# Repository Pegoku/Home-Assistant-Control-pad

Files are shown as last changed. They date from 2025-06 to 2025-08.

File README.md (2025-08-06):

# Home-Assistant-Control-pad

This is a programmable Home Assistant Control Pad. It can control 4 Home assistant devices at a time, and has 4 togglable screens/zones (in total 16 devices). It uses buttons and rotary encoders to enable and control other HASS devices. It also has an OLED Display (1.33") to display the status of the devices. It is battery powered, it contains a 1800mAh Li-Po. The device uses an ESP32-S2 and ESPHome.

## Why I made it?

I made this project as I wanted an easy and fast way to control the "smart" devices I have made. I'm making quite a few ESPHome devices and wanted something to control most of them easily.

## Features

- Controls Home Assistant entities (lights, switches, etc.)
- Over-the-air (OTA) updates

## Images

Final Build: 

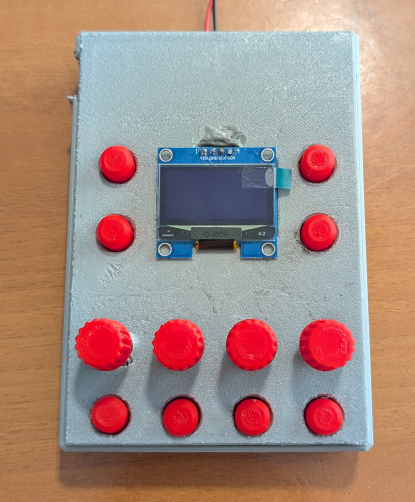
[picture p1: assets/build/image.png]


<details>
  <summary>Case</summary>

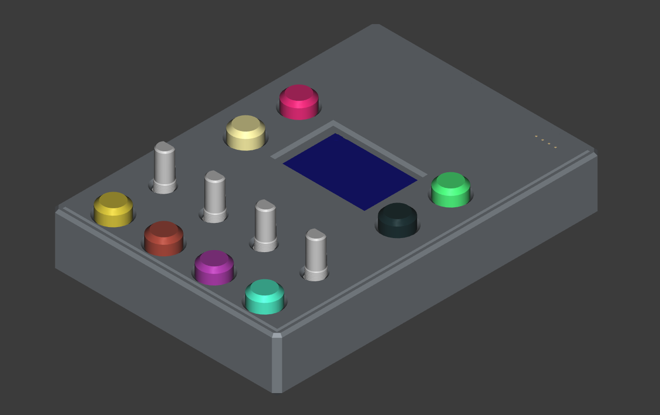
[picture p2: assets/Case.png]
Final


</details>
<details>
  <summary>Schematic</summary>
  
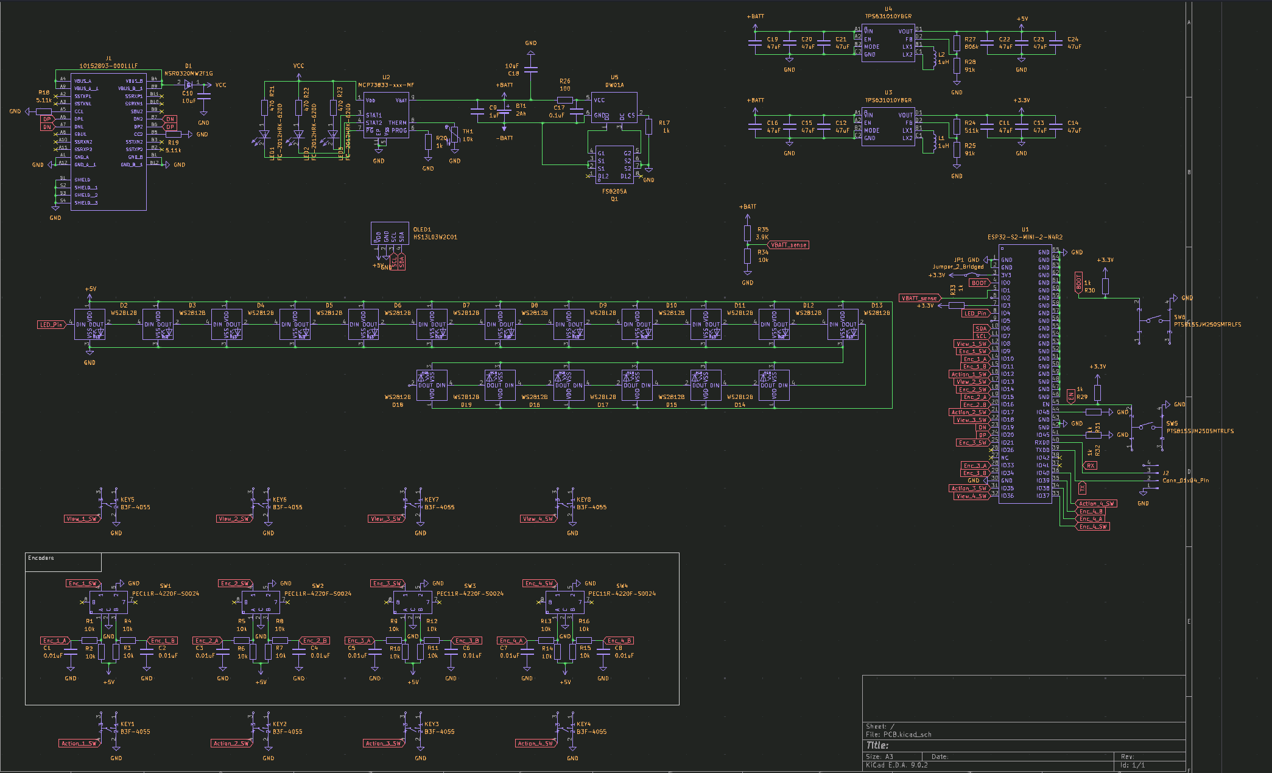
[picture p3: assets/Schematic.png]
schematic


</details>
<details>
  <summary>PCB</summary>

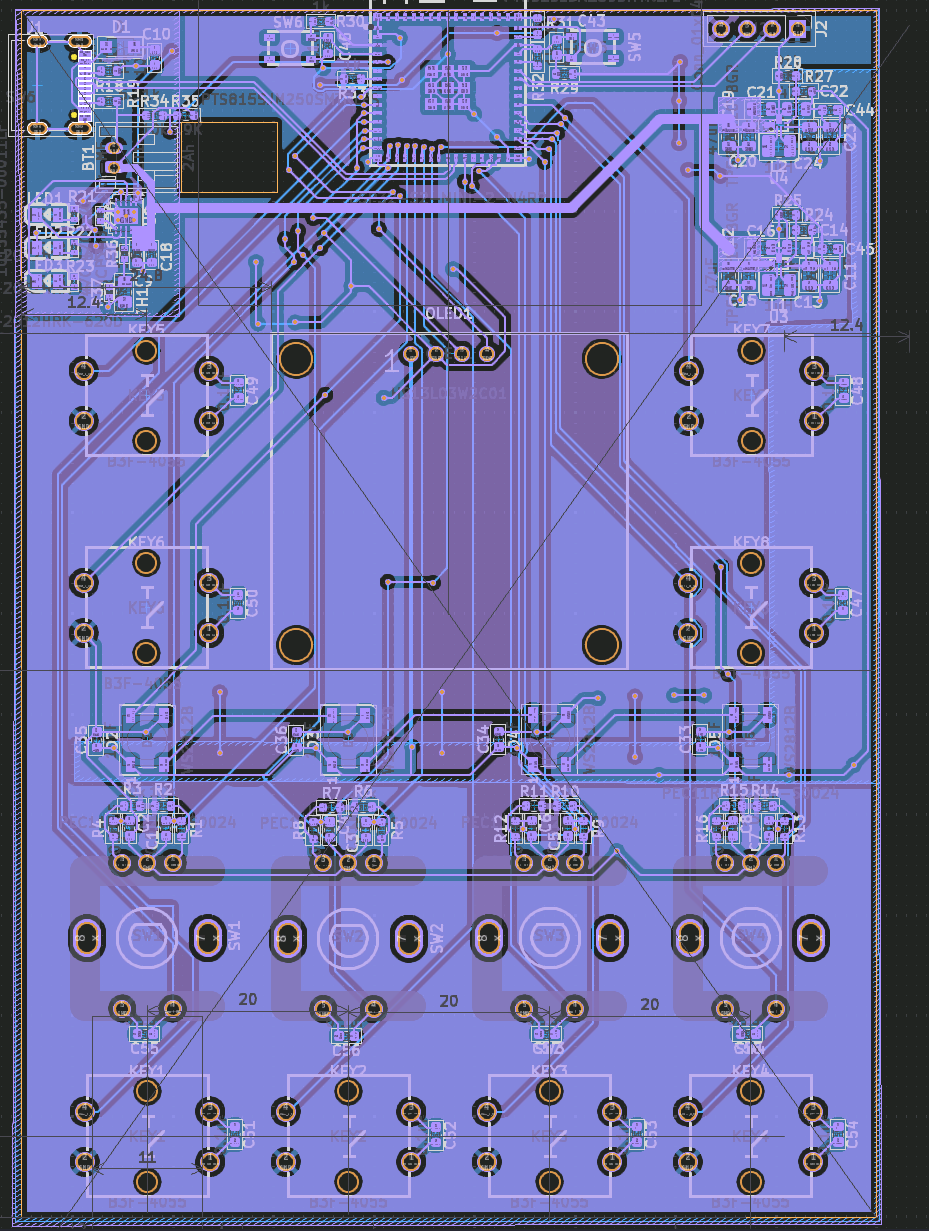
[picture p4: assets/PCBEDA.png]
PCB design

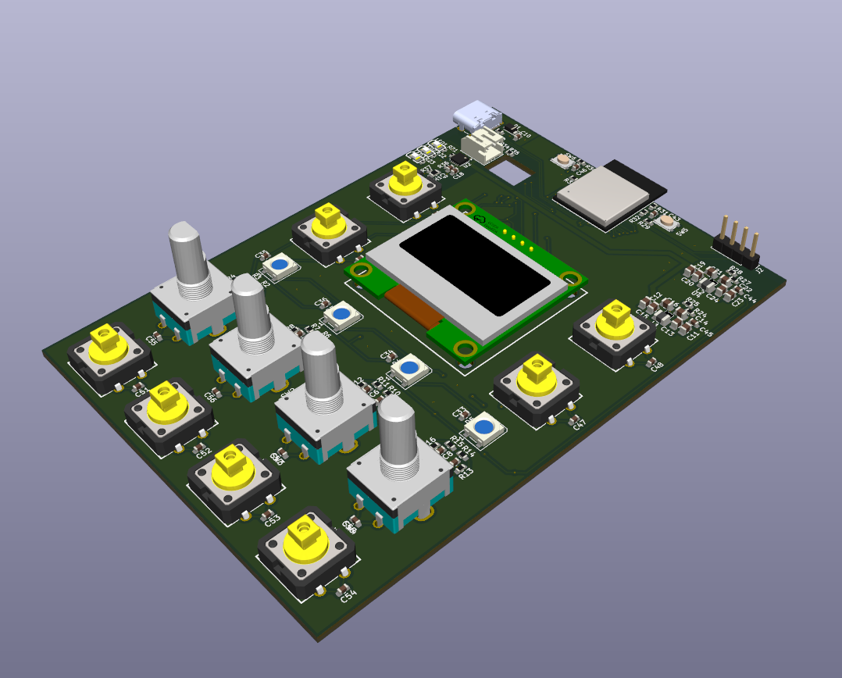
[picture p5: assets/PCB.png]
PCB render


</details>

## BOM

| Index | Part Number | What the item is for in your project | Description | Pack Quantity | ID | Unit Price | Total Price | Total |
| ----- | --- | --- | --- | --- | --- | --- | --- | --- |
| 1 | PMEG10010ELRX | Reverse polarity protection | DIODE SCHOTTKY 100V 1A SOD123W | 2 | 1727+AC0-2394+AC0-1+AC0-ND | $0.27 | $0.54 | $133.08 |
| 2 | DFE252012P+AC0-1R0M+AD0-P2 | Inductor for buck+AC0-boost | FIXED IND 1UH 3.2A 0.042OHM SMD | 3 | 490+AC0-10647+AC0-1+AC0-ND | $0.22 | $0.66 |
| 3 | LS R976+AC0-NR+AC0-1+AC0-0+AC0-20+AC0-R18 | Led indication | LED RED DIFFUSED 0805 SMD | 3 | 475+AC0-LSR976+AC0-NR+AC0-1CT+AC0-ND | $0.15 | $0.45 |
| 4 | LG R971+AC0-KN+AC0-1+AC0-0+AC0-20+AC0-R18 | Led indication | LED GREEN DIFFUSED 0805 SMD | 3 | 475+AC0-LGR971+AC0-KN+AC0-1CT+AC0-ND | $0.15 | $0.45 |
| 5 | LTST+AC0-C170KSKT | Led indication | LED YELLOW CLEAR SMD | 3 | 160+AC0-1416+AC0-1+AC0-ND | $0.17 | $0.51 |
| 6 | RMCF0603JT10K0 | Passive | RES 10K OHM 5% 1/10W 0603 | 22 | RMCF0603JT10K0CT+AC0-ND | $0.02 | $0.42 |
| 7 | CRCW06035K11FKEAC | Passive | RES 5.11K OHM 1% 1/10W 0603 | 3 | 541+AC0-5491+AC0-1+AC0-ND | $0.10 | $0.30 |
| 8 | RC0402FR+AC0-071KL | Passive | RES 1K OHM 1% 1/16W 0402 | 2 | 311+AC0-1.00KLRCT+AC0-ND | $0.10 | $0.20 |
| 9 | RC0402FR+AC0-07470RL | Passive | RES 470 OHM 1% 1/16W 0402 | 4 | 311+AC0-470LRCT+AC0-ND | $0.10 | $0.40 |
| 10 | RC0603FR+AC0-07511KL | Passive | RES 511K OHM 1% 1/10W 0603 | 2 | 311+AC0-511KHRCT+AC0-ND | $0.10 | $0.20 |
| 11 | RC0603FR+AC0-0791KL | Passive | RES 91K OHM 1% 1/10W 0603 | 3 | 311+AC0-91.0KHRCT+AC0-ND | $0.10 | $0.30 |
| 12 | RC0603FR+AC0-07806KL | Passive | RES 806K OHM 1% 1/10W 0603 | 2 | 311+AC0-806KHRCT+AC0-ND | $0.10 | $0.20 |
| 13 | RC0603FR+AC0-071KL | Passive | RES 1K OHM 1% 1/10W 0603 | 13 | 311+AC0-1.00KHRCT+AC0-ND | $0.01 | $0.12 |
| 14 | RC0603FR+AC0-073K9L | Passive | RES 3.9K OHM 1% 1/10W 0603 | 2 | 311+AC0-3.90KHRCT+AC0-ND | $0.10 | $0.20 |
| 15 | RC0402FR+AC0-071K54L | Passive | RES 1.54K OHM 1% 1/16W 0402 | 2 | YAG3040CT+AC0-ND | $0.10 | $0.20 |
| 16 | RC0402FR+AC0-0769K8L | Passive | RES 69.8K OHM 1% 1/16W 0402 | 2 | YAG3216CT+AC0-ND | $0.10 | $0.20 |
| 17 | PEC11R+AC0-4220F+AC0-S0024 | Rotate action | ROTARY ENCODER MECHANICAL 24PPR | 7 | PEC11R+AC0-4220F+AC0-S0024+AC0-ND | $1.89 | $13.23 |
| 18 | PTS815SJG250SMTR LFS | Esp32 buttons | SWITCH TACTILE SPST+AC0-NO 0.05A 12V | 3 | CKN12217+AC0-1+AC0-ND | $0.28 | $0.84 |
| 19 | TX08F103F3435ER | NTC Thermistor | THERMISTOR 0805 10K/3435 | 2 | 273+AC0-TX08F103F3435ERCT+AC0-ND | $0.12 | $0.24 |
| 20 | ESP32+AC0-S2+AC0-MINI+AC0-2+AC0-N4R2 | MCU | RF TXRX MOD WIFI PCB TRACE SMD | 2 | 1965+AC0-ESP32+AC0-S2+AC0-MINI+AC0-2+AC0-N4R2CT+AC0-ND | $4.31 | $8.62 |
| 21 | MCP73833T+AC0-FCI/MF | Battery charger | IC BATT CONTRL LI+AC0-ION 1CEL 10DFN | 2 | MCP73833T+AC0-FCI/MFCT+AC0-ND | $1.14 | $2.28 |
| 22 | TPS631010YBGR | Buck+AC0-Boost | IC REG BUCK BST ADJ 1.5A 8DSBGA | 3 | 296+AC0-TPS631010YBGRCT+AC0-ND | $1.29 | $3.87 |
| 23 | C0603C103J5REC7411 | Passive | CAP CER SMD 0603 .01UF 5% X7R 50 | 13 | 399+AC0-17568+AC0-1+AC0-ND | $0.10 | $1.33 |
| 24 | C0603C104J5REC7411 | Passive | CAP CER 0603 | 20 | 399+AC0-C0603C104J5REC7411CT+AC0-ND | $0.11 | $2.24 |
| 25 | CL10A105KQ8NNNC | Passive | CAP CER 1UF 6.3V X5R 0603 | 2 | 1276+AC0-1036+AC0-1+AC0-ND | $0.10 | $0.20 |
| 26 | CL10A106KQ8NNNC | Passive | CAP CER 10UF 6.3V X5R 0603 | 13 | 1276+AC0-1038+AC0-1+AC0-ND | $0.03 | $0.39 |
| 27 | CL21A476MQYNNNG | Passive | CAP CER 47UF 6.3V X5R 0805 | 15 | 1276+AC0-6467+AC0-1+AC0-ND | $0.16 | $2.37 |
| 28 | 16347 | Led indication | ADDRESS LED RED/GRN/BLUE | 5 | 1568+AC0-16347CT+AC0-ND | $0.68 | $3.40 |
| 29 | B3F+AC0-4055 | Push Action | SWITCH TACTILE SPST+AC0-NO 0.05A 24V | 10 | SW414+AC0-ND | $0.42 | $4.23 |
| 30 | S2B+AC0-PH+AC0-K+AC0-S | Battery connector | CONN HEADER R/A 2POS 2MM | 2 | 455+AC0-1719+AC0-ND | $0.11 | $0.22 |
| 31 | PCB | PCB | | 1 | https://aisler.net | $42.57 | $42.57 |
| 32 | Battery | Power Source | 103450 1800mAh | 1 | https://www.ebay.es/itm/255510046348 | $15.44 | $15.44 |
| 33 | Display | Displays The UI | I2C display | 1 | https://es.aliexpress.com/item/1005006862867338.html | $2.62 | $2.62 |
| 34 | Rubber Feet | Adds friction to the base so it doesn+IBk-t slip | | 1 | https://es.aliexpress.com/item/1005005275590870.html | $3.11 | $3.11 |
| 35 | ELEGOO PLA filament | Printing case | | 1 | https://www.amazon.es/-/en/Filament-Printer-Dimensional-Accuracy-Printers/dp/B0CD77VHBZ | $20.53 | $20.53 |

## Configuration

Remember to set your secrets in [secrets.yaml](Code/secrets.example.yaml).

All firmware configuration lives in [code.yaml](Code/code.yaml):
PS: This configuration is for reference only, The final configuration will be for the ESP32-S2. You'll also have to configure the devices you want to control in Home Assistant.
```yaml
esphome:
  name: controlpad
  friendly_name: ControlPad

esp32:
  board: esp32-c3-devkitm-1
  framework:
    type: arduino

# Enable logging
logger:

# Enable Home Assistant API
api:
  encryption:
    key: !secret api_key

ota:
  - platform: esphome
    password: !secret ota_password

wifi:
  ssid: !secret wifi_ssid
  password: !secret wifi_password

  # Enable fallback hotspot (captive portal) in case wifi connection fails
  ap:
    ssid: "Controlpad Fallback Hotspot"
    password: "wHjqyQOLnaPa"

globals:
  - id: page_active
    type: int
    initial_value: "0"

i2c:
  sda: GPIO6
  scl: GPIO7
  frequency: 800kHz
  scan: true

binary_sensor:
  - platform: gpio
    pin:
      number: GPIO2
      mode: INPUT_PULLUP
      inverted: true
    name: "Button1"
    on_press:
      - display.page.show: page1
      - lambda: |-
          id(page_active) = 1;

  - platform: gpio
    pin:
      number: GPIO4
      mode: INPUT_PULLUP
      inverted: true
    name: "Button2"
    on_press:
      - display.page.show: page2
      - lambda: |-
          id(page_active) = 2;

  - platform: gpio
    pin:
      number: GPIO21
      mode: INPUT_PULLUP
      inverted: true
    name: "toggle1"
    on_press:
      then:
        - if:
            condition:
              lambda: |-
                return id(page_active) == 1;
            then:
              - homeassistant.service:
                  service: light.toggle
                  data:
                    entity_id: light.led_controller_1_light_bar

sensor:
  - platform: homeassistant
    name: "Bar Light Brightness"
    id: led_controller_1_light_bar_brightness
    entity_id: light.led_controller_1_light_bar
    attribute: brightness
    unit_of_measurement: "%"
    filters:
      - lambda: |-
          if (isnan(x)) return 0.0f;
          return int(x * 100.0f / 255.0f);

  - platform: adc
    pin: GPIO3
    name: "potentiometer1"
    id: potentiometer1
    attenuation: 12db # allow 0–3.3 V range
    update_interval: 20ms
    unit_of_measurement: "%"
    filters:
      - sliding_window_moving_average:
          window_size: 10
          send_every: 5
      - lambda: |-
          if (isnan(x)) return 0.0f;
          int pot_val = int(x * 100.0f / 2.9f);
          if (pot_val > 100) pot_val = 100;
          return pot_val;
      - delta: 1.0

    on_value:
      then:
        - if:
            condition:
              lambda: |-
                return id(page_active) == 1;
            then:
              - homeassistant.service:
                  service: light.turn_on
                  data:
                    entity_id: light.led_controller_1_light_bar
                    brightness_pct: !lambda "return (int)x;"

# SH1106 128×64 over I2C
display:
  - platform: ssd1306_i2c
    model: SH1106 128x64
    id: display1
    address: 0x3C
    rotation: 0
    update_interval: 100ms
    pages:
      - id: page1
        lambda: |-
          int val1 = int((id(led_controller_1_light_bar_brightness).state / 100.0f) * 31);
          if (val1 != 0) {
            val1 += 1;
          }
          it.filled_rectangle(10, 64-val1, 5, 33);

          // it.printf(0, 0, id(font1), "%.0f%%", id(led_controller_1_light_bar_brightness).state);
      - id: page2
        lambda: |-
          it.print(0, 10, id(font1), "This is page 2!");
          it.filled_rectangle(10, 20, 80, 5);

font:
  - file: "gfonts://Ubuntu"
    id: font1
    size: 20

captive_portal:
```

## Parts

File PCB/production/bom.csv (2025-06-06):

 | Footprint | Quantity | Value | LCSC Part #
BT1 | JST_PH_S2B-PH-K_1x02_P2.00mm_Horizontal | 1 | 2Ah
C1, C2, C3, C4, C5, C6, C7, C8 | 0603 | 8 | 0.01uF
C10, C18, C33, C34, C35, C36 | 0603 | 6 | 10uF
C11, C12, C13, C14, C15, C16, C19, C20, C21, C22, C23, C24 | 0805 | 12 | 47uF
C43, C44, C45, C46, C47, C48, C49, C50, C51, C52, C53, C54, C55, C56, C57, C58 | 0603 | 16 | 0.1uF
C9 | 0603 | 1 | 1uF
D1 | Nexperia_CFP3_SOD-123W | 1 | D
D2, D3, D4, D5 | LED_WS2812B_PLCC4_5.0x5.0mm_P3.2mm | 4 | WS2812B
J1 | AMPHENOL_10155435-00011LF | 1 | 10155435-00011LF
J2 | PinHeader_1x04_P2.54mm_Vertical | 1 | Conn_01x04_Pin
KEY1, KEY2, KEY3, KEY4, KEY5, KEY6, KEY7, KEY8 | KEY-TH_4P-L12.0-W12.0-P5.00-LS13.4-EH | 8 | B3F-4055 | C84931
L1, L2 | 1008 | 2 | 1uH
LED1, LED2, LED3 | LED0805-R-RD | 3 | FC-2012HRK-620D | C84256
OLED1 | OLED-TH_L35.4-W33.5_HS13L03W2C01 | 1 | HS13L03W2C01 | C7465997
R1, R10, R11, R12, R13, R14, R15, R16, R2, R3, R34, R4, R5, R6, R7, R8, R9 | 0603 | 17 | 10k
R18, R19 | 0603 | 2 | 5.11k
R20 | 0402 | 1 | 1k
R21, R22, R23 | 0402 | 3 | 470
R24 | 0603 | 1 | 511k
R25, R28 | 0603 | 2 | 91k
R27 | 0603 | 1 | 806k
R29, R30, R31, R32, R33 | 0603 | 5 | 1k
R35 | 0603 | 1 | 3.9K
R36 | 0402 | 1 | 1.54k
R37 | 0402 | 1 | 69.8k
SW1, SW2, SW3, SW4 | SW-TH_5P-L12.5-W13.4-P2.50-LS14.5-EH13.2 | 4 | PEC11R-4220F-S0024 | C143797
SW5, SW6 | KEY-SMD_4P-L4.2-W3.25-P2.15-TL | 2 | PTS815SJM250SMTRLFS | C2689510
TH1 | 0805 | 1 | 10k
U1 | WIFI-SMD_ESP32-MINI-1-N4 | 1 | ESP32-S2-MINI-2-N4R2 | C3013908
U2 | DFN-10-1EP_3x3mm_P0.5mm_EP1.58x2.35mm | 1 | MCP73833-xxx-MF
U3, U4 | WLCSP-8_L1.8-W1.0-R4-C2-P0.40-BR | 2 | TPS631010YBGR | C6719123

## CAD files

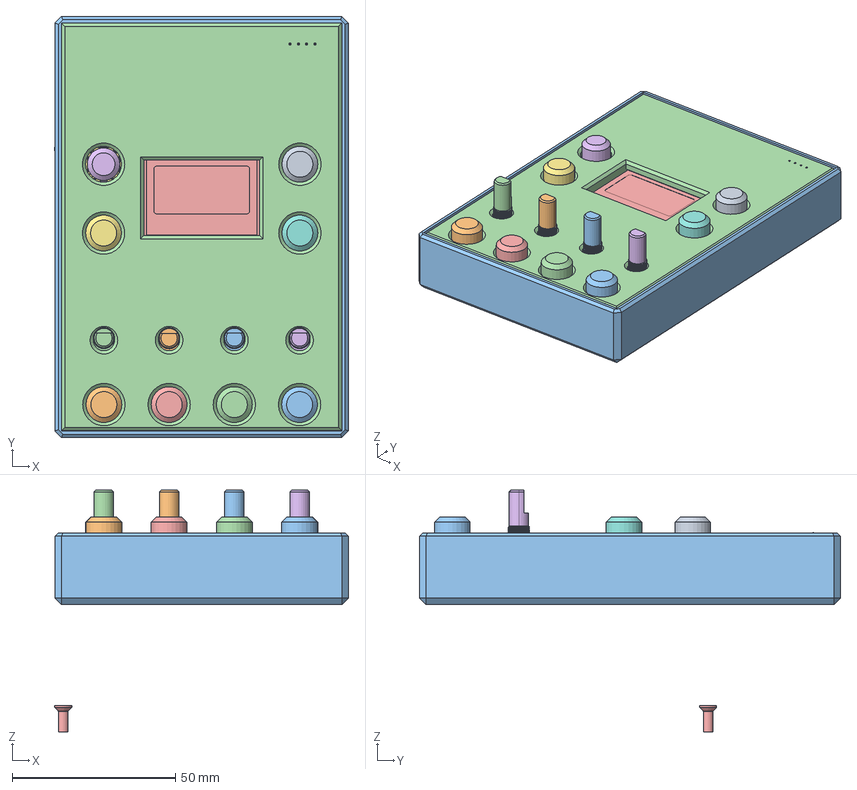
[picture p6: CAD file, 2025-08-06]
CAD/Case.FCStd
90.2 x 129.1 x 74.1 mm
Battery
R_0402_1005Metric006
SW-TH_5P-L12.5-W13.4-P2.50-LS14.5-EH13.006
WLCSP-8_L1.8-W1.0-R4-C2-P0.40-BR002
WIFI-SMD_ESP32-MINI-1-N005
KEY-TH_4P-L12.0-W12.0-H7.5-LS12.5-P5.008
DFN-10-1EP_3x3mm_P0.5mm_EP1.55x2.48mm001
C_0603_1608Metric031
C_0603_1608Metric032
LED_WS2812B_PLCC4_5.0x5.0mm_P3.2mm004
R_0603_1608Metric029
C_0805_2012Metric012
C_0603_1608Metric033
C_0603_1608Metric034
R_0603_1608Metric030
R_0402_1005Metric007
R_0603_1608Metric031
R_0603_1608Metric032
C_0603_1608Metric035
LED0805-RD003
OLED-TH_L35.4-W33.5_HS13L03W2C002
C_0603_1608Metric036
C_0603_1608Metric037
R_0603_1608Metric033
C_0603_1608Metric038
C_0805_2012Metric013
C_0805_2012Metric014
R_0603_1608Metric034
KEY-TH_4P-L12.0-W12.0-H7.5-LS12.5-P5.009
R_0603_1608Metric035
R_0603_1608Metric036
C_0805_2012Metric015
C_0603_1608Metric039
C_0603_1608Metric040
R_0603_1608Metric037
C_0603_1608Metric041
LED_WS2812B_PLCC4_5.0x5.0mm_P3.2mm005
R_0603_1608Metric038
C_0603_1608Metric042
C_0805_2012Metric016
R_0603_1608Metric039
LED0805-RD004
KEY-SMD_4P-L4.2-W3.25-P2.15-TL002
PCB 1.43.002
LED0805-RD005
C_0603_1608Metric043
C_0805_2012Metric017
R_0603_1608Metric040
KEY-TH_4P-L12.0-W12.0-H7.5-LS12.5-P5.010
WLCSP-8_L1.8-W1.0-R4-C2-P0.40-BR003
R_0402_1005Metric008
KEY-TH_4P-L12.0-W12.0-H7.5-LS12.5-P5.011
R_0402_1005Metric009
R_0603_1608Metric041
C_0805_2012Metric018
R_0603_1608Metric042
C_0603_1608Metric044
R_0603_1608Metric043
KEY-TH_4P-L12.0-W12.0-H7.5-LS12.5-P5.012
R_0603_1608Metric044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

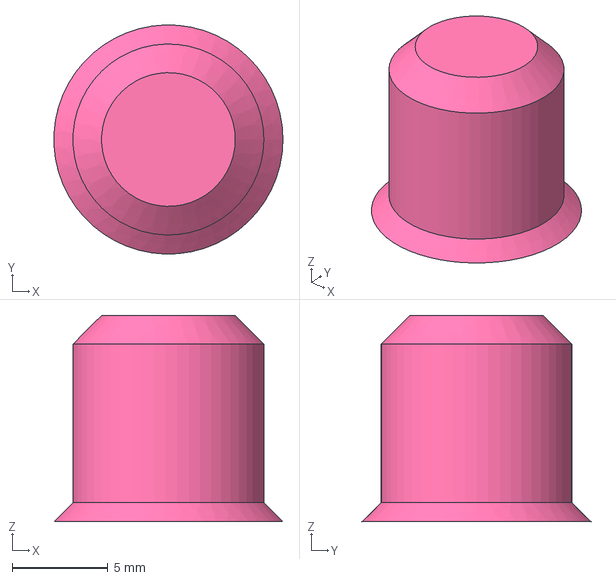
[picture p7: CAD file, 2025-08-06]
CAD/Button.step
12.0 x 12.0 x 10.8 mm

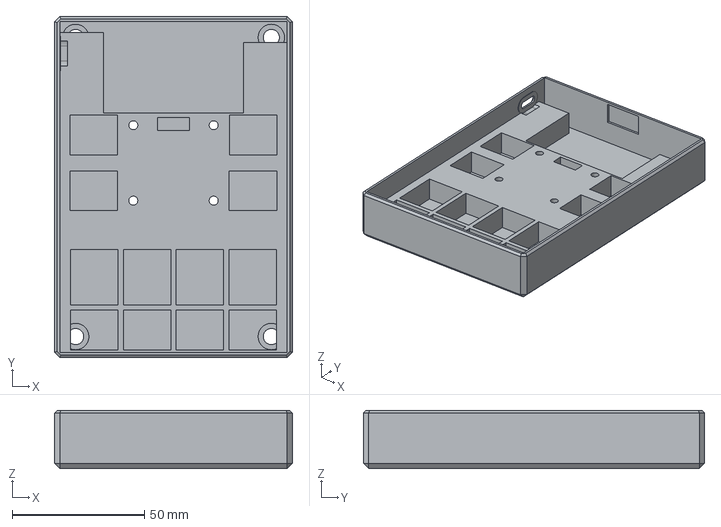
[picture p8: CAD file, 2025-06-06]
CAD/CaseBottom.step
90.0 x 129.1 x 22.0 mm

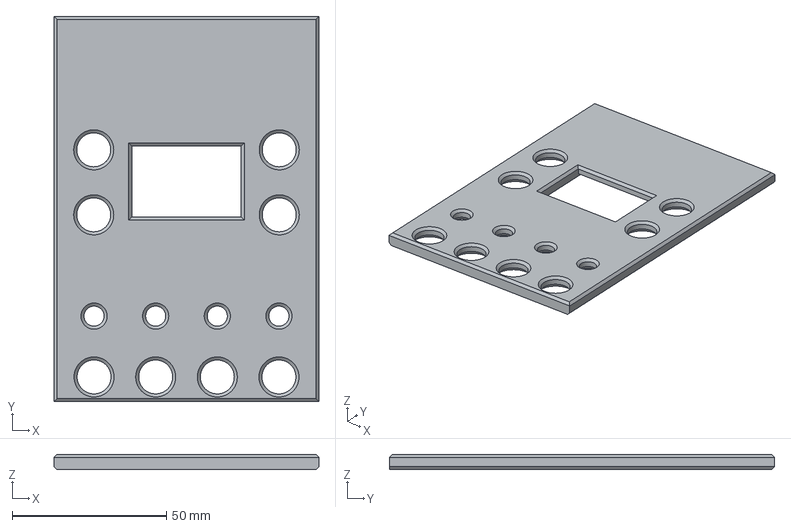
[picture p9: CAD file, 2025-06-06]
CAD/CaseTop.step
86.0 x 125.0 x 5.00 mm

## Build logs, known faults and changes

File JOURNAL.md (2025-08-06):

---
title: "Home Assistant Control Pad"
author: "Pegoku"
description: "An ESP32-S2 based Control pad for Home Assistant."
created_at: "2025-05-18"
total_time_spent: "54h"
---

# May 18th: Sketch and first prototype!
To start, I did a simple sketch of what I would like for the Pad to be, and what features it should have. I wanted to keep it simple, so I focused on the most important features that would make it useful for controlling Home Assistant devices.

Features I ended up with:

1* Mode/View toggle buttons

2* Adjustment knobs (pots or encoders)

3* Action buttons

4* Toggle switches (Not used)

5* USB-C Charge port

6* display info (OLED)



I also tested how to drive an I2C dispay with the an ESP32-C3 and use multiple Screens activated with buttons.
Used this as reference: [SSD1306](https://esphome.io/components/display/ssd1306)



**Total time spent: 3h**

# May 19th: Using potentiometers and dynamically updating the display
I wanted to use potentiometers to adjust values, so I started testing how to read them with the ESP32-C3. I found that using the ADC pins wasn't as easy as I thought, as I had to set `attenuation: 12db` to allow 0~3.3V range.



PS: The potentiometer later broke and replaced it with a smaller one

**Total time spent: 4h**

# May 20th: Adding action buttons and indicator bar.
Next I wanted to add action buttons so I could trigger or toggle items in Home Assistant. To test, I used it to turn on and off a light.



I also added coded an indicator bar to show the current value of the device.



PS: While coding the bar, I found a bug (may also be user error) but it seems like if use the same variable twice for the same screen item(eg. rectangle). The esp32 refuses to connect to wifi, it also doesn't respond to actions (eg. button presses)

**Total time spent: 3h**

# May 21st: Find limitations of ESP32-C3
I started wiring the remaining action buttons and potentiometers, when I realised that the ESP32-C3 has a limitation of 11 GPIO pins. 3 of which are ADC. This means I'm unable to use all the buttons, potentiometers and the OLED display at the same time. So when designing the PCB I'll have to switch to the ESP32-S2.



**Total time spent: 2h**

# May 22nd: Start designing the Schematic
I started designing the schematic for the PCB, using the ESP32-S2. I used the ESP32-S2-MINI-2-N4R2, PEC11R-4220F-S0024 (rotary encoders) and B3F-4055 (tactile switches).

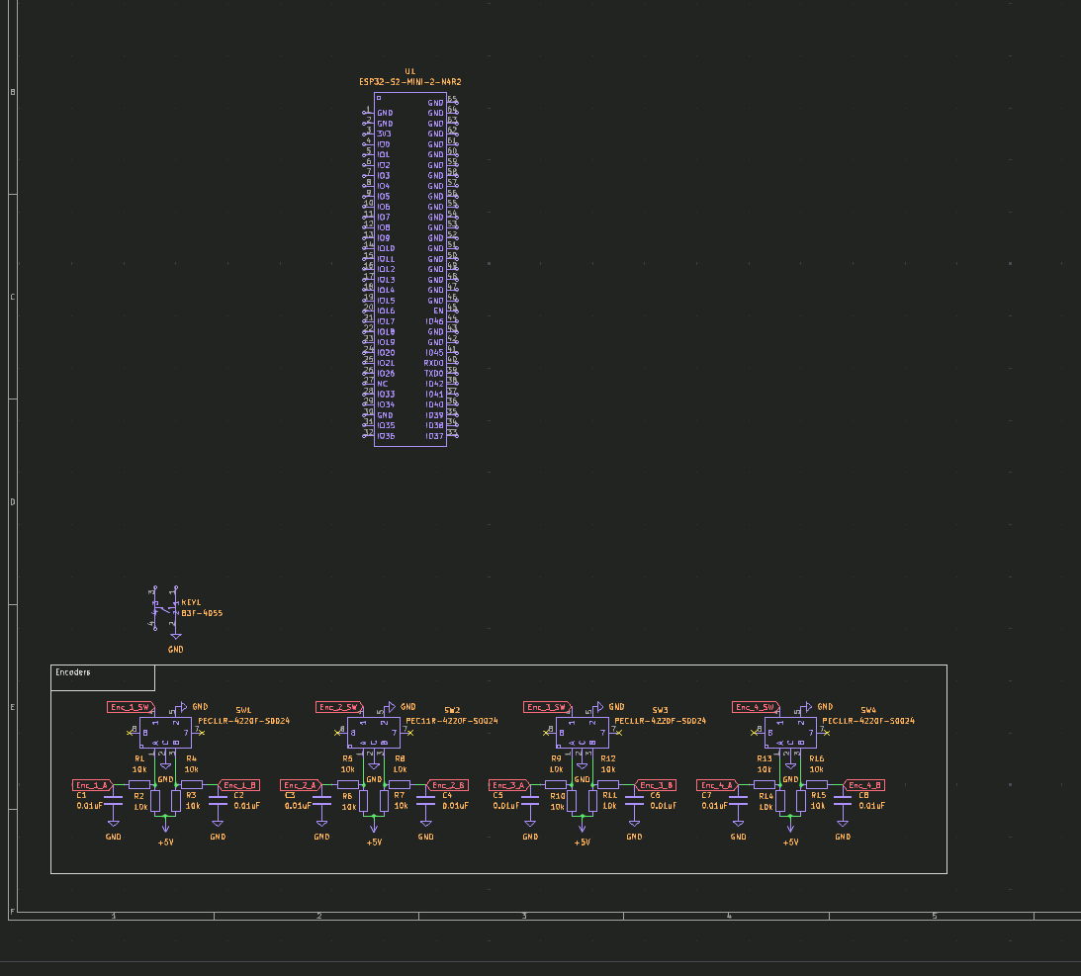
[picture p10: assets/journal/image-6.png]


**Total time spent: 2h**

# May 23nd: Finish Schematic and start PCB design
I selected the Buck-Boost (TPS631010YBGR) for both the 5V and 3.3V rails. I also added an USB-C port and Battery charging (MCP73833).

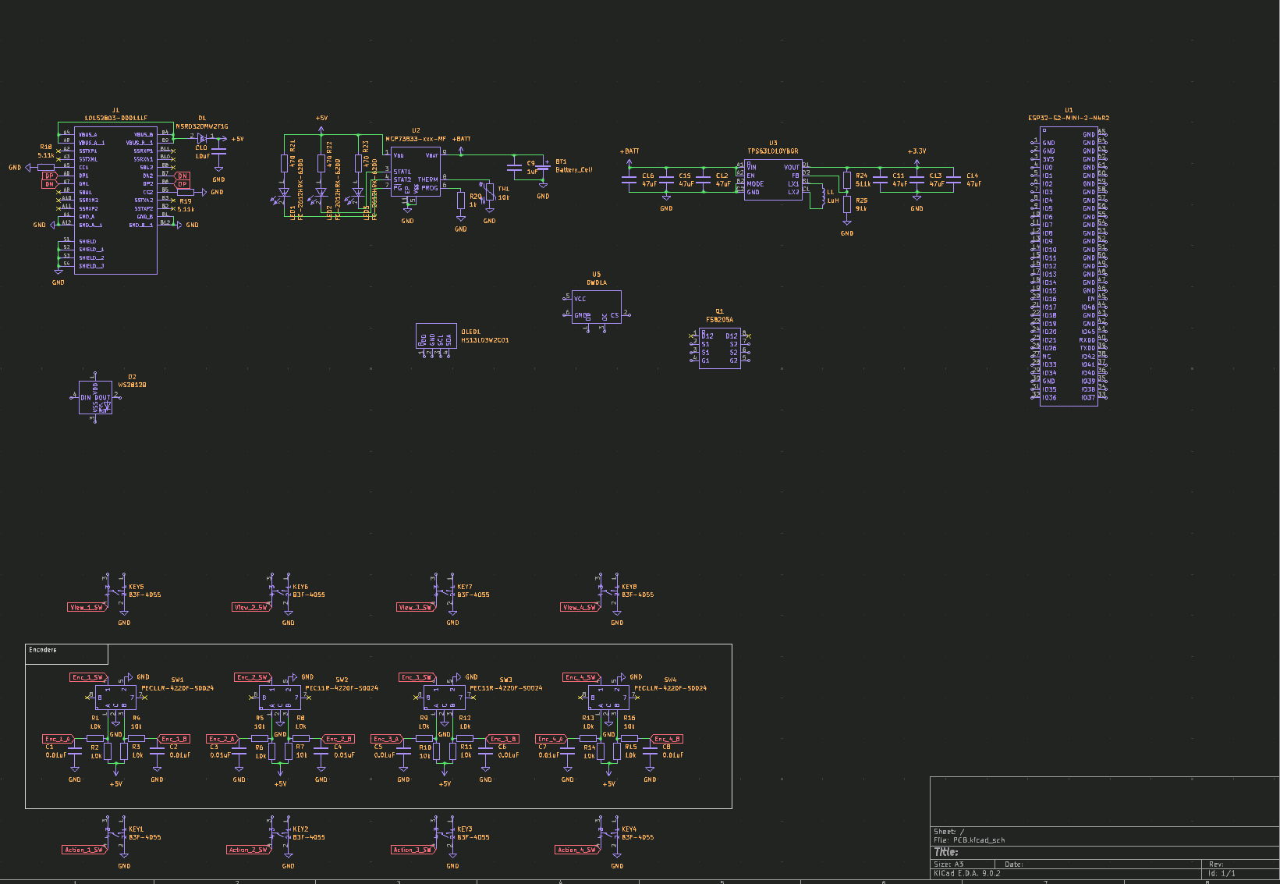
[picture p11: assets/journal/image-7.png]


Then I added 18 neopixel LEDs to the PCB, which will only 4 ended up being used in the final design. the OLED display, Battery voltage sense and battery protection DWQ1A.



**Total time spent: 5h**

# May 24th: Continue PCB design and choose battery
I continued the PCB design, placing the components. I also added a battery to use, I wanted to use a 18650 but I thought it would be too big so I went with a [1800mAh 103450 LiPo](https://www.ebay.es/itm/255510046348) with integrated BMS. I also added a removed the battery protection circuit from the board as the battery already has one.

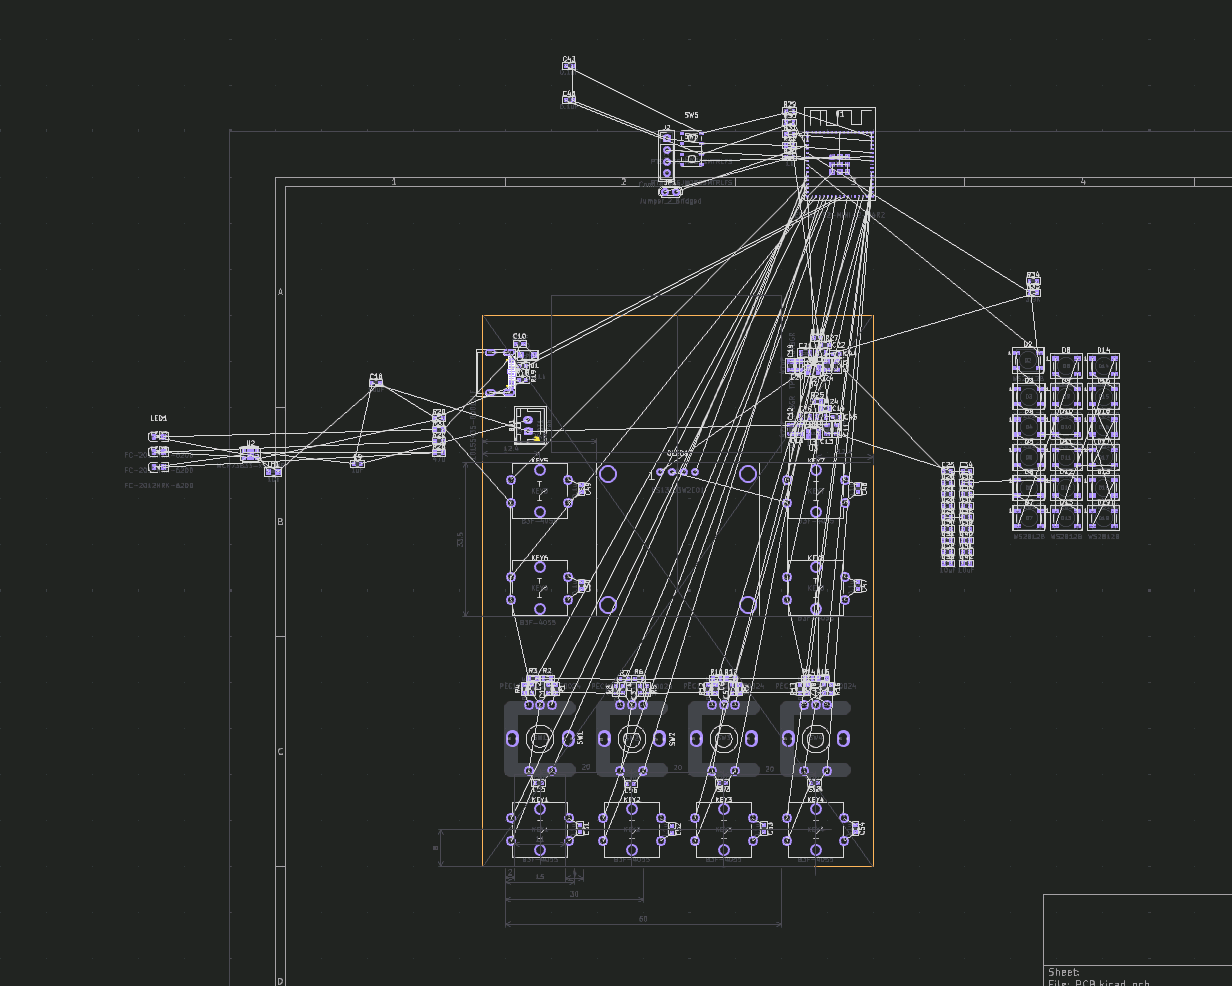
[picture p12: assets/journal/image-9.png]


**Total time spent: 3h**

# May 25th: Finish PCB design! Also, start case design
I continued placing all the components, and finally finished the PCB design!

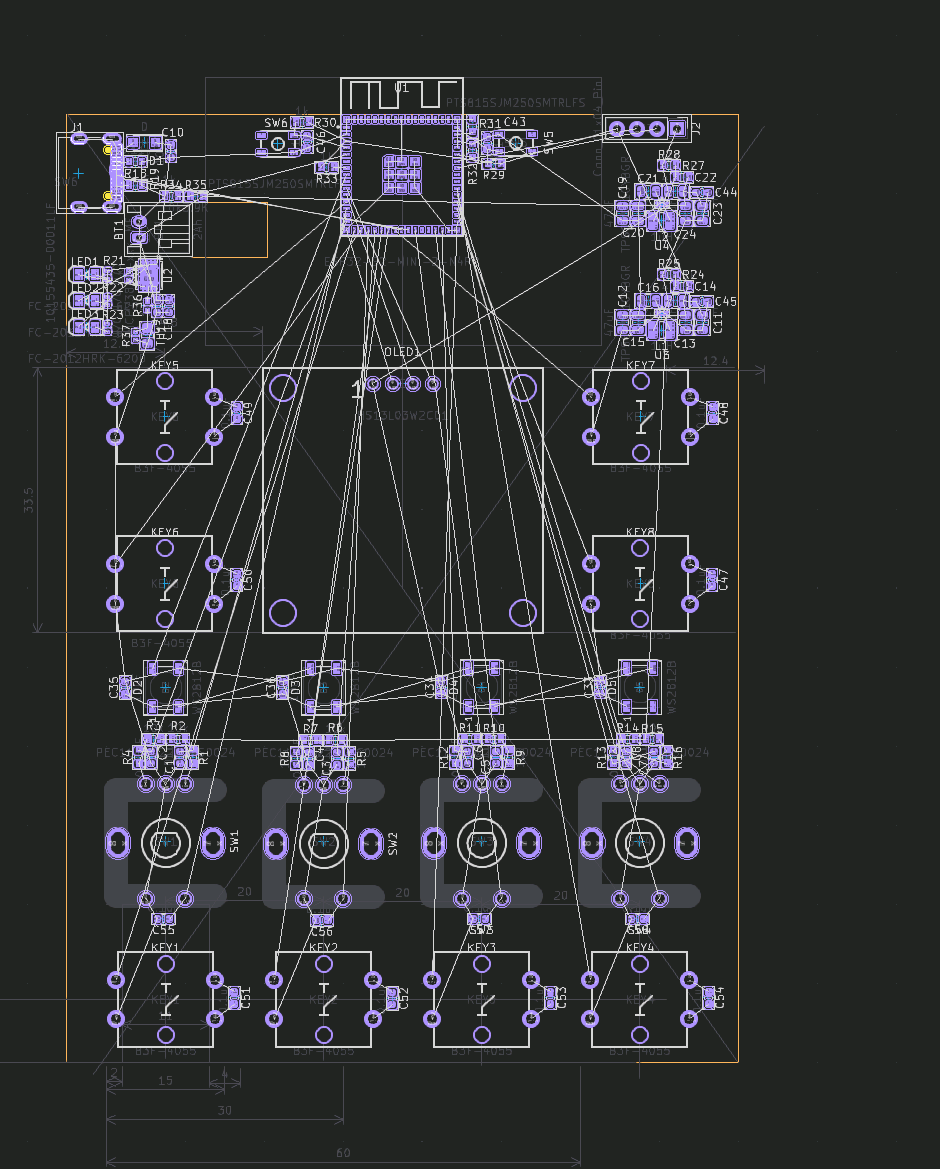
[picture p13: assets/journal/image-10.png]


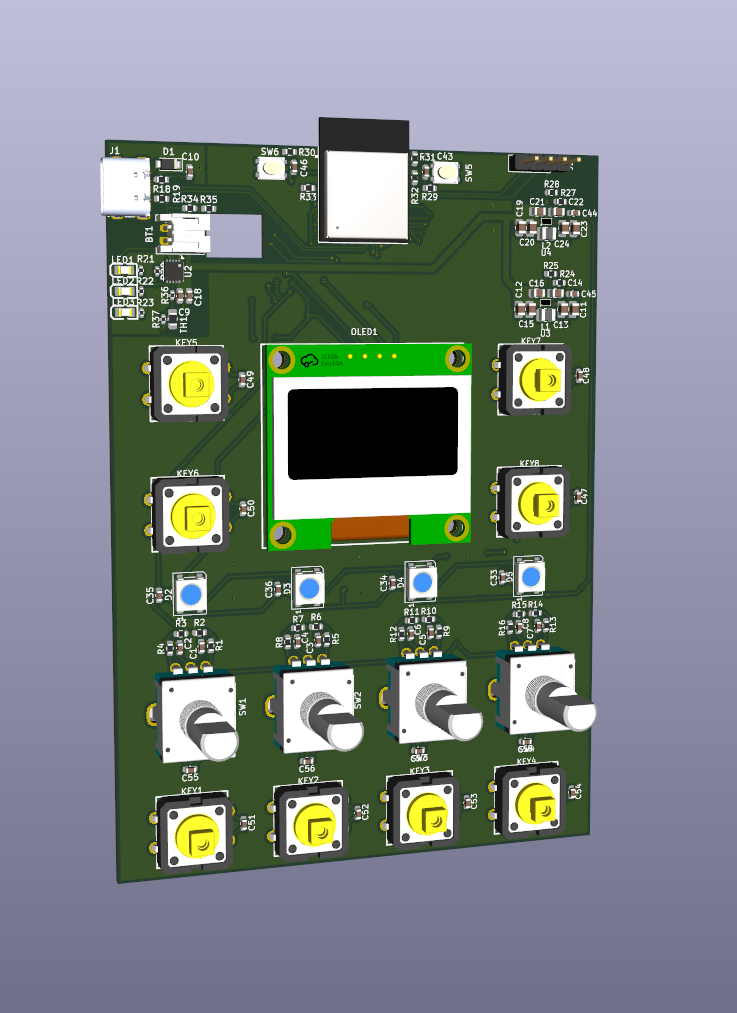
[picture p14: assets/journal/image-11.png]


Once I finished the PCB design, I started designing the case in FreeCAD.

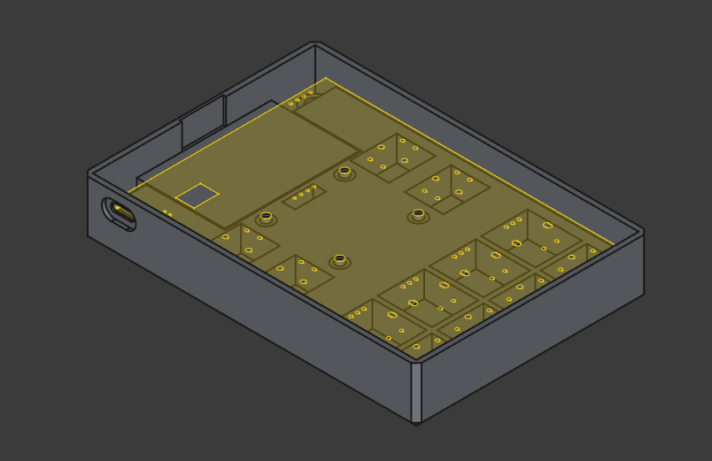
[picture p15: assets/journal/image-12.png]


**Total time spent: 8h**

# June 1st: Finish case design!
I finished the case. Added buttons and a slot for the USB-C port. I also added holes for the buttons (which I also designed) and rotary encoders, also added a slot for the OLED display.

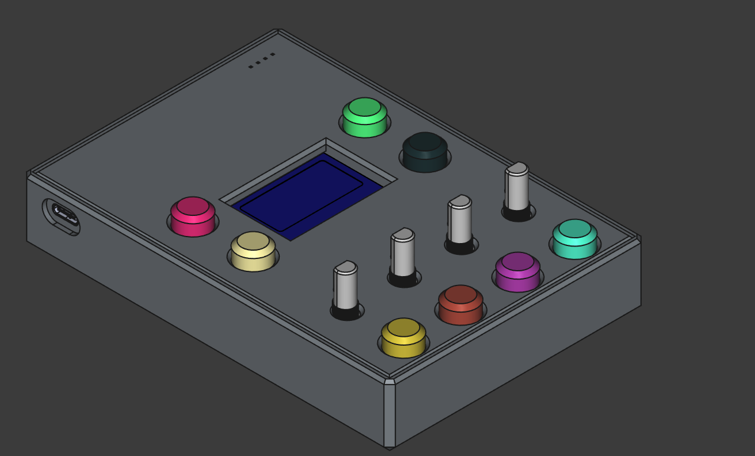
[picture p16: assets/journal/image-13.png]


**Total time spent: 4h**

# July 4th: soldering the PCB
Today I soldered the PCBs, it was pretty straightforward, except for some tiny components like the buck-boost converter which were a bit tricky to solder, as I was unable to see the IC labels.
It was hard, but eventually I ended up with a fully soldered PCB!

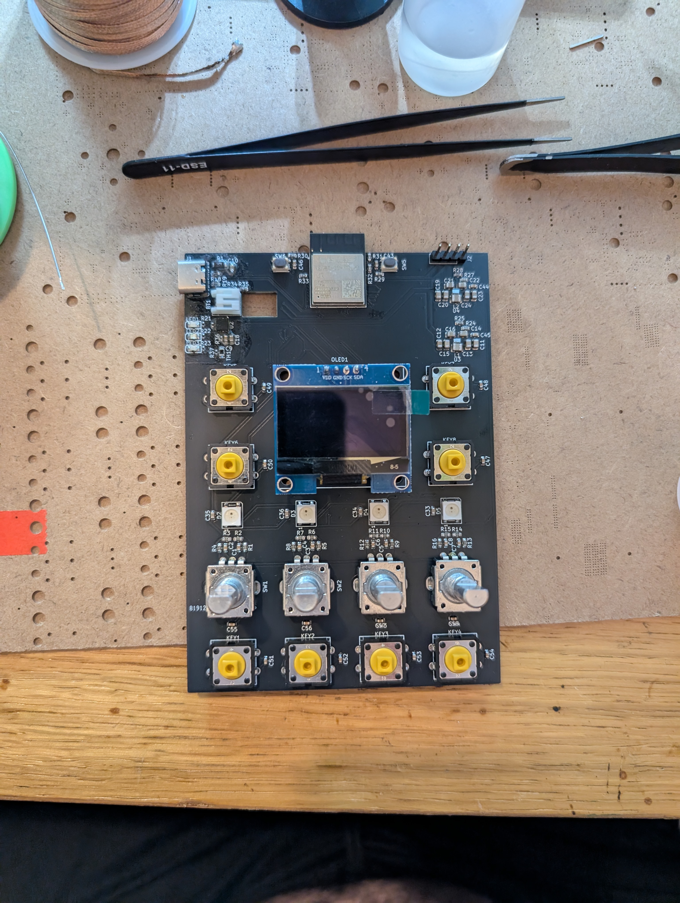
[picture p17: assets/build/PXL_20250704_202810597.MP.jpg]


Then, I tested the battery charging circuit, and it worked!!! I was able to charge the battery safely to 4.2V! (don't know how the leds work though, but idrc, it just works)

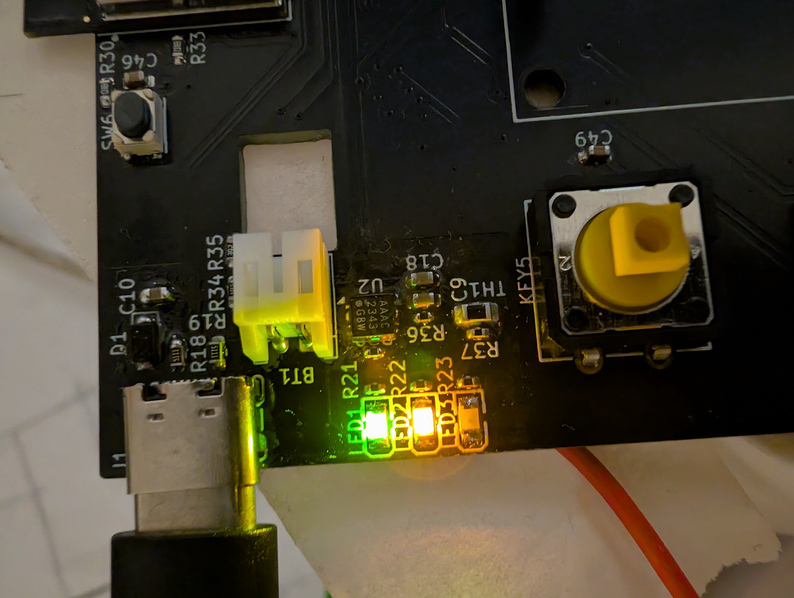
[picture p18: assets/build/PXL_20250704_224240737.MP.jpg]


**Total time spent: 6h**

# August 2nd: 
Quite a long time has passed, but it was worth it! I went to the best hackathon ever, Undercity! It was an amazing experience, I met a lot of amazing people and learned a lot. I also got to build a cool project.
Continuing from where I left off. I started coding the firmware for the control pad. Luckily I had already done most of the work, as I already had a working version for the ESP32-C3, so I just had to adapt it to the ESP32-S2. I also added support for the rotary encoders. 
Sadly, the code wasn't working as expected. The rotary encoders registered, but they weren't showing on the display, so I debugged it for a while, I even thought it was a power issue, which in part it was, as I discovered the 5V boost wasn't behaving correctly. And that's why I tried wiring the display to 3.3V, with no luck.

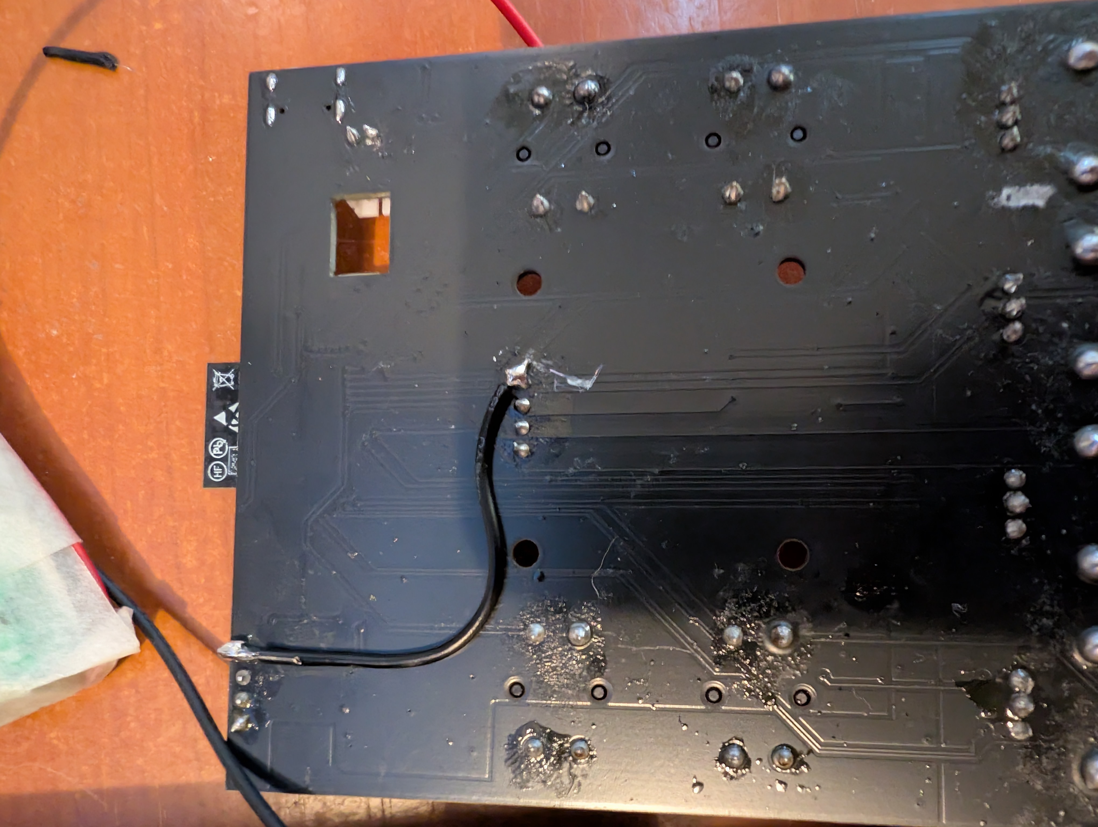
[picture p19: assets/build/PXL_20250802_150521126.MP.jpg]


Then, I debugged the code, and found that the issue was with the I2C bus. It seems that I wired the I2C pins incorrectly as no devices were being detected. 
I left it for the day, as I was tired and frustrated.
**Total time spent: 6h**

# August 3rd: Debugging the I2C bus
Today was getting close to the deadline to ship projects to highway, so I did a but of _multitasking_ and worked on this prject and the Smart desk lamp at the same time.
I still thought the problem with the display was a power issue, so I inspected the PCB and found that it had an 3.3V LDO, and I just bridged it so the display would get the direct 3.3V from the buck-boost converter. Sadly, it didn't help. I also tried with a diferent display, but it didn't work either. As a las resort, I configured the GPIOs 18 and 36 to be the I2C pins, they were for buttons, but I didn't need them for now. But again, that didn't work either, yes, I added pull-up resistors to the SDA and SCL lines, but it still didn't work. I was getting really frustrated, so I left it for the day.
I think I'll just not use the display for now. It'll just be able to control 4 devices, but I think It'll be enough, as I don't really have that many "smart" devices at home.

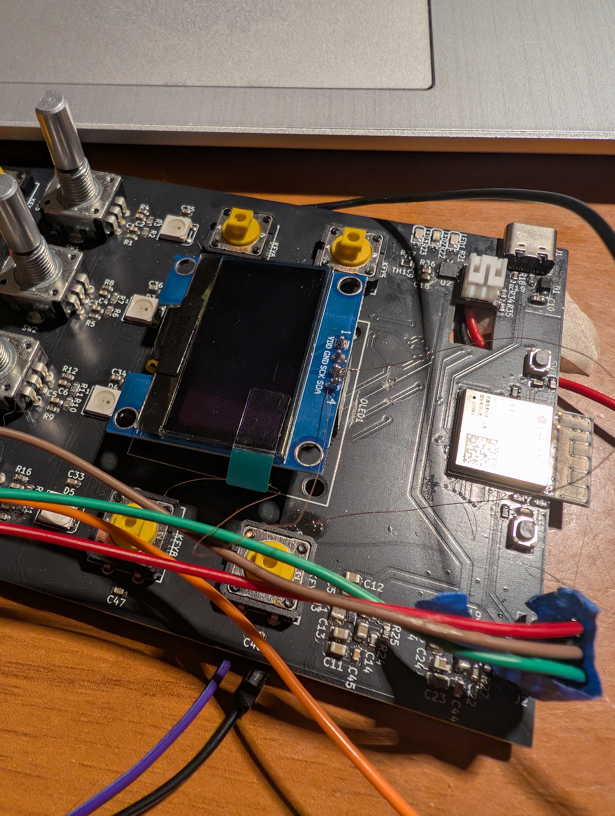
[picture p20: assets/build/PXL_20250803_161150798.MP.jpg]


**Total time spent: 4h**

# August 5th: Final assembly
Today I assembled the case. Sadly not everything fit as I expected, so I had to do some modifications to the case. 
This are all the modifications I had to do:

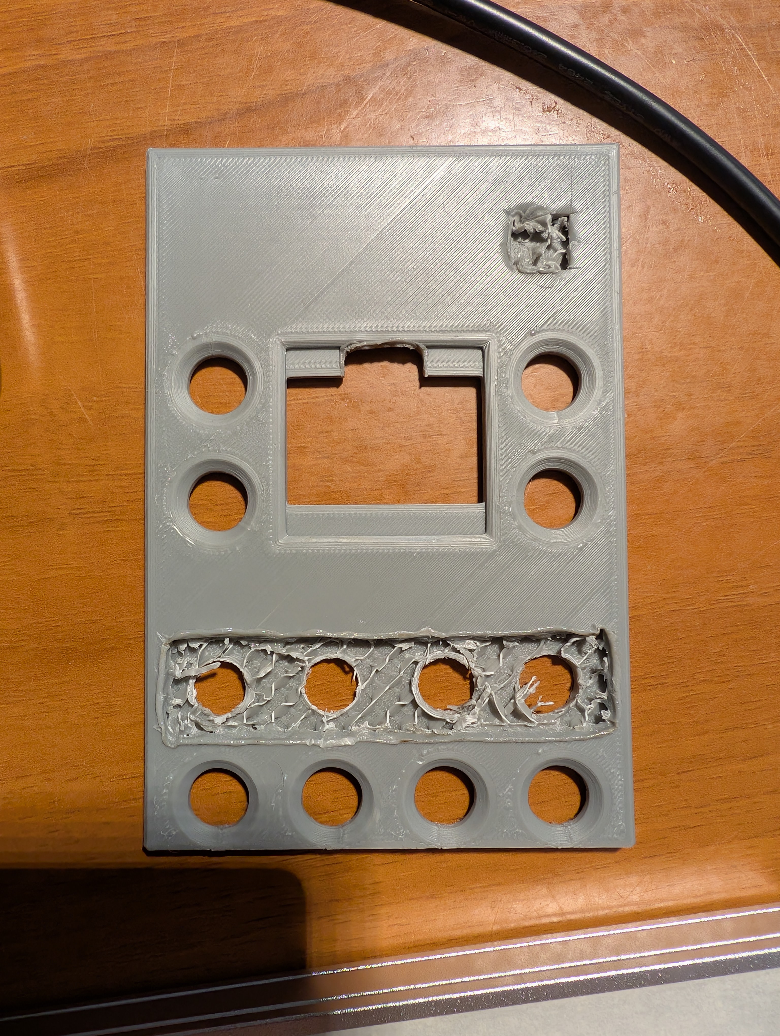
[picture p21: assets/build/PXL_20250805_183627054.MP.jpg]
 

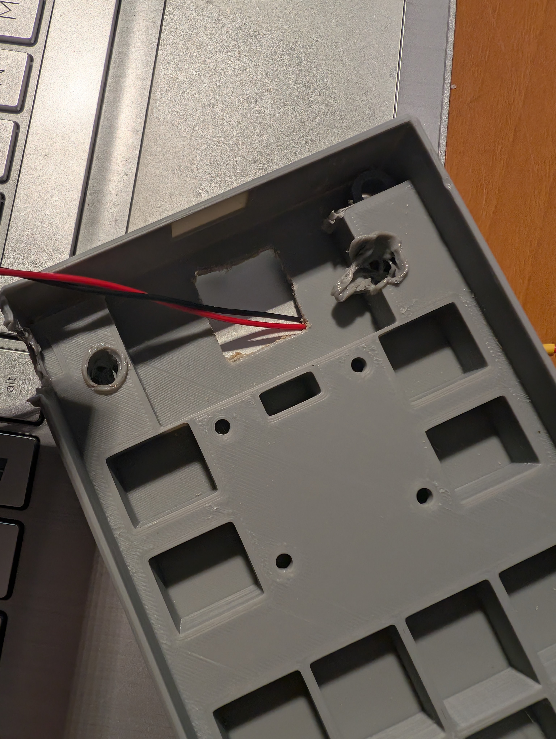
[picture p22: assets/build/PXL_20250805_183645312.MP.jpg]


**Total time spent: 4h**

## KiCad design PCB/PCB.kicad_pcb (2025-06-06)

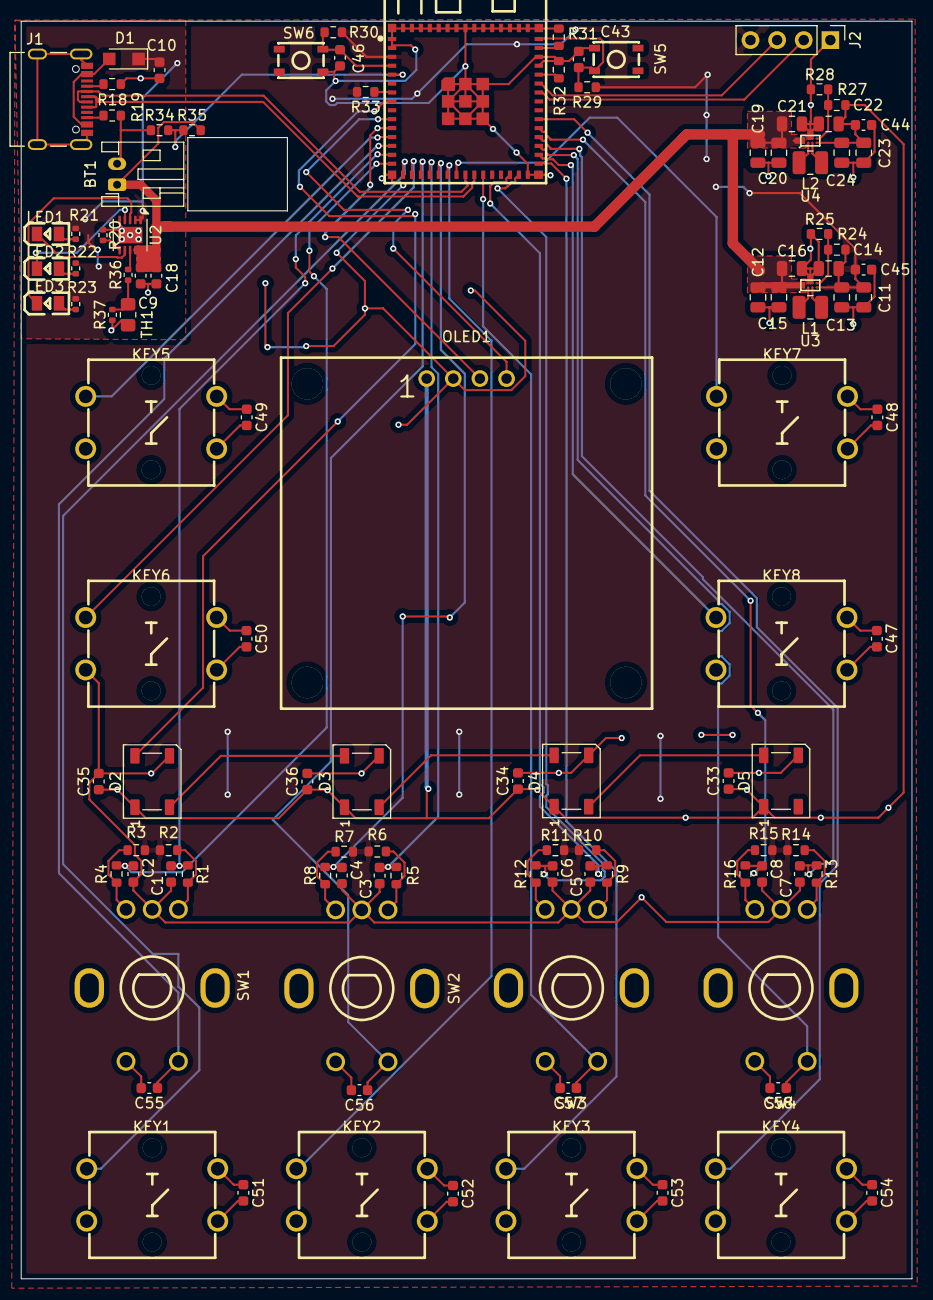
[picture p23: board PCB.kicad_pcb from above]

Board: 2 copper layers, 85.0 x 120.0 mm, 111 parts (0 on the bottom side), 83 nets.

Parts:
BT1: 2Ah; JST_PH_S2B-PH-K_1x02_P2.00mm_Horizontal
C1, C2, C3, C4, C5, C6, C7, C8: 0.01uF; C_0603_1608Metric
C9: 1uF; C_0603_1608Metric
C10, C18, C33, C34, C35, C36: 10uF; C_0603_1608Metric
C11, C12, C13, C14, C15, C16, C19, C20, C21, C22, C23, C24: 47uF; C_0805_2012Metric
C43, C44, C45, C46, C47, C48, C49, C50, C51, C52, C53, C54, C55, C56, C57, C58: 0.1uF; C_0603_1608Metric
D1: D; Nexperia_CFP3_SOD-123W
D2, D3, D4, D5: WS2812B; LED_WS2812B_PLCC4_5.0x5.0mm_P3.2mm
J1: 10155435-00011LF; AMPHENOL_10155435-00011LF
J2: Conn_01x04_Pin; PinHeader_1x04_P2.54mm_Vertical
KEY1, KEY2, KEY3, KEY4, KEY5, KEY6, KEY7, KEY8: B3F-4055; KEY-TH_4P-L12.0-W12.0-P5.00-LS13.4-EH
L1, L2: 1uH; L_1008_2520Metric
LED1, LED2, LED3: FC-2012HRK-620D; LED0805-R-RD
OLED1: HS13L03W2C01; OLED-TH_L35.4-W33.5_HS13L03W2C01
R1, R2, R3, R4, R5, R6, R7, R8, R9, R10, R11, R12, R13, R14, R15, R16, R34: 10k; R_0603_1608Metric
R18, R19: 5.11k; R_0603_1608Metric
R20: 1k; R_0402_1005Metric
R21, R22, R23: 470; R_0402_1005Metric
R24: 511k; R_0603_1608Metric
R25, R28: 91k; R_0603_1608Metric
R27: 806k; R_0603_1608Metric
R29, R30, R31, R32, R33: 1k; R_0603_1608Metric
R35: 3.9K; R_0603_1608Metric
R36: 1.54k; R_0402_1005Metric
R37: 69.8k; R_0402_1005Metric
SW1, SW2, SW3, SW4: PEC11R-4220F-S0024; SW-TH_5P-L12.5-W13.4-P2.50-LS14.5-EH13.2
SW5, SW6: PTS815SJM250SMTRLFS; KEY-SMD_4P-L4.2-W3.25-P2.15-TL
TH1: 10k; R_0805_2012Metric_Pad1.20x1.40mm_HandSolder
U1: ESP32-S2-MINI-2-N4R2; WIFI-SMD_ESP32-MINI-1-N4
U2: MCP73833-xxx-MF; DFN-10-1EP_3x3mm_P0.5mm_EP1.58x2.35mm
U3, U4: TPS631010YBGR; WLCSP-8_L1.8-W1.0-R4-C2-P0.40-BR

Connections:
+3.3V: C11.1, C13.1, C14.1, C45.1, J2.4, R2.2, R3.2, R6.2, R7.2, R10.2, R11.2, R14.2, R15.2, R24.1, R29.1, R30.1, R33.2, U1.3 (3V3), U3.D1 (VOUT)
+5V: C22.1, C23.1, C24.1, C33.1, C34.1, C35.1, C36.1, C44.1, D2.1 (VDD), D3.1 (VDD), D4.1 (VDD), D5.1 (VDD), OLED1.1 (VDD), R27.1, U4.D1 (VOUT)
+BATT: BT1.1 (+), C9.1, C12.1, C15.1, C16.1, C18.1, C19.1, C20.1, C21.1, R35.2, U2.9 (V_{BAT}), U2.10 (V_{BAT}), U3.A1 (VIN), U3.A2 (EN), U4.A1 (VIN), U4.A2 (EN)
Action_1_SW: KEY1.4, U1.16 (IO12)
Action_2_SW: KEY2.4, U1.21 (IO17)
Action_3_SW: KEY3.4, U1.31 (IO35)
Action_4_SW: KEY4.4, U1.36 (IO40)
BOOT: C46.1, R30.2, SW6.2, U1.4 (IO0)
DN: J1.A7 (DN1), J1.B7 (DN2), U1.23 (IO19)
DP: J1.A6 (DP1), J1.B6 (DP2), U1.24 (IO20)
EN: C43.1, R29.2, SW5.2, U1.45 (EN)
Enc_1_A: C1.1, R1.1, U1.14 (IO10)
Enc_1_B: C2.1, R4.2, U1.15 (IO11)
Enc_1_SW: C55.1, SW1.4 (1), U1.13 (IO9)
Enc_2_A: C3.1, R5.1, U1.19 (IO15)
Enc_2_B: C4.1, R8.2, U1.20 (IO16)
Enc_2_SW: C56.1, SW2.4 (1), U1.18 (IO14)
Enc_3_A: C5.1, R9.1, U1.28 (IO33)
Enc_3_B: C6.1, R12.2, U1.29 (IO34)
Enc_3_SW: C57.1, SW3.4 (1), U1.25 (IO21)
Enc_4_A: C7.1, R13.1, U1.34 (IO38)
Enc_4_B: C8.1, R16.2, U1.35 (IO39)
Enc_4_SW: C58.1, SW4.4 (1), U1.33 (IO37)
GND: BT1.2 (-), C1.2, C2.2, C3.2, C4.2, C5.2, C6.2, C7.2, C8.2, C9.2, C10.2, C11.2, C12.2, C13.2, C14.2, C15.2, C16.2, C18.2, C19.2, C20.2, C21.2, C22.2, C23.2, C24.2, C33.2, C34.2, C35.2, C36.2, C43.2, C44.2, C45.2, C46.2, C55.2, C56.2, C57.2, C58.2, D2.3 (VSS), D3.3 (VSS), D4.3 (VSS), D5.3 (VSS), J1.A1_B12 (GND), J1.B1_A12 (GND__1), J1.SH1 (SHIELD), J1.SH2 (SHIELD__1), J1.SH3 (SHIELD__2), J1.SH4 (SHIELD__3), J2.1, KEY1.2, KEY2.2, KEY3.2, KEY4.2, KEY5.2, KEY6.2, KEY7.2, KEY8.2, OLED1.2 (GND), R18.1, R19.2, R20.1, R25.2, R28.2, R31.2, R32.2, R34.1, R37.1, SW1.2 (C), SW1.5 (2), SW2.2 (C), SW2.5 (2), SW3.2 (C), SW3.5 (2), SW4.2 (C), SW4.5 (2), SW5.4, SW6.4, TH1.2, U1.1 (GND), U1.2 (GND), U1.30 (GND), U1.42 (GND), U1.43 (GND), U1.46 (GND), U1.47 (GND), U1.48 (GND), U1.49 (GND), U1.50 (GND), U1.51 (GND), U1.52 (GND), U1.53 (GND), U1.54 (GND), U1.55 (GND), U1.56 (GND), U1.57 (GND), U1.58 (GND), U1.59 (GND), U1.60 (GND), U1.61 (GND), U1.62 (GND), U1.63 (GND), U1.64 (GND), U1.65 (GND), U2.5 (V_{SS}), U2.11 (EP), U3.B2 (MODE), U3.C2 (GND), U4.B2 (MODE), U4.C2 (GND)
LED_Pin: D2.4 (DIN), U1.8 (IO4)
unnamed: C47.1, KEY8.3
unnamed: C47.2, KEY8.1
unnamed: C48.1, KEY7.3
unnamed: C48.2, KEY7.1
unnamed: C49.1, KEY5.3
unnamed: C49.2, KEY5.1
unnamed: C50.1, KEY6.3
unnamed: C50.2, KEY6.1
unnamed: C51.1, KEY1.3
unnamed: C51.2, KEY1.1
unnamed: C52.1, KEY2.3
unnamed: C52.2, KEY2.1
unnamed: C53.1, KEY3.3
unnamed: C53.2, KEY3.1
unnamed: C54.1, KEY4.3
unnamed: C54.2, KEY4.1
unnamed: D1.2 (A), J1.A4_B9 (VBUS), J1.B4_A9 (VBUS__1)
unnamed: D2.2 (DOUT), D3.4 (DIN)
unnamed: D3.2 (DOUT), D4.4 (DIN)
unnamed: D4.2 (DOUT), D5.4 (DIN)
unnamed: J1.A5 (CC1), R18.2
unnamed: J1.B5 (CC2), R19.1
unnamed: LED1.1 (+), R21.1
unnamed: LED1.2 (-), U2.7 (~PG)
unnamed: LED2.1 (+), R22.1
unnamed: LED2.2 (-), U2.4 (STAT2)
unnamed: LED3.1 (+), R23.1
unnamed: LED3.2 (-), U2.3 (STAT1)
unnamed: R36.1, R37.2, TH1.1
unnamed: R1.2, R2.1, SW1.1 (A)
unnamed: R3.1, R4.1, SW1.3 (B)
unnamed: R5.2, R6.1, SW2.1 (A)
unnamed: R7.1, R8.1, SW2.3 (B)
unnamed: R9.2, R10.1, SW3.1 (A)
unnamed: R11.1, R12.1, SW3.3 (B)
unnamed: R13.2, R14.1, SW4.1 (A)
unnamed: R15.1, R16.1, SW4.3 (B)
unnamed: R33.1, U1.7 (IO3)
unnamed: R32.1, U1.41 (IO45)
unnamed: R31.1, U1.44 (IO46)
unnamed: R20.2, U2.6 (PROG)
unnamed: R36.2, U2.8 (THERM)
unnamed: R24.2, R25.1, U3.D2 (FB)
unnamed: L1.1, U3.B1 (LX1)
unnamed: L1.2, U3.C1 (LX2)
unnamed: R27.2, R28.1, U4.D2 (FB)
unnamed: L2.1, U4.B1 (LX1)
unnamed: L2.2, U4.C1 (LX2)
RX: J2.3, U1.40 (RXD0)
SCL: OLED1.3 (SCL), U1.11 (IO7)
SDA: OLED1.4 (SDA), U1.10 (IO6)
TX: J2.2, U1.39 (TXD0)
VBATT_sense: R34.2, R35.1, U1.5 (IO1)
VCC: C10.1, D1.1 (K), R21.2, R22.2, R23.2, U2.1 (V_{DD}), U2.2 (V_{DD})
View_1_SW: KEY5.4, U1.12 (IO8)
View_2_SW: KEY6.4, U1.17 (IO13)
View_3_SW: KEY7.4, U1.22 (IO18)
View_4_SW: KEY8.4, U1.32 (IO36)

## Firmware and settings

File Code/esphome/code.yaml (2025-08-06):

esphome:
  name: controlpad2
  friendly_name: ControlPad2

esp32:
  board: esp32-s2-saola-1
  framework:
    type: esp-idf

# Enable logging
logger:
  level: DEBUG

# Enable Home Assistant API
api:
  encryption:
    key: "FYaG0+DJO9rJaQOu7bJyjQT0Jpvoz5ws2u+Z/V0jZZs="

ota:
  - platform: esphome
    password: "7e8d125e2b9de0759ffb5e9158697196"

wifi:
  ssid: !secret wifi_ssid_m
  password: !secret wifi_password_m

  # Enable fallback hotspot (captive portal) in case wifi connection fails
  ap:
    ssid: "Controlpad2 Fallback Hotspot"
    password: "BriUVetpsnHe"

    

globals:
  - id: page_active
    type: int
    initial_value: '0'

i2c:
  sda: GPIO18
  scl: GPIO36
  frequency: 100kHz
  scan: true

binary_sensor:
  - platform: gpio
    pin:
      number: GPIO8
      mode: INPUT_PULLUP
      inverted: true
    name: "Button1"
    on_press:
      - display.page.show: page1
      - lambda: |-
          id(page_active) = 1;  

  - platform: gpio
    pin:
      number: GPIO13
      mode: INPUT_PULLUP
      inverted: true
    name: "Button2"
    on_press:
      - display.page.show: page2
      - lambda: |-
          id(page_active) = 2;
  
  - platform: gpio
    pin:
      number: GPIO21
      mode: INPUT_PULLUP
      inverted: true
    name: "toggle1"
    on_press:
      then:
      - if:
          condition:
            lambda: |-
              return id(page_active) == 1;
          then:
            - homeassistant.service:
                service: light.toggle
                data:
                  entity_id: light.led_controller_1_light_bar

sensor:
  - platform: homeassistant
    name: "Bar Light Brightness"
    id: led_controller_1_light_bar_brightness
    entity_id: light.led_controller_1_light_bar
    attribute: brightness
    unit_of_measurement: "%"
    filters:
      - lambda: |-
          if (isnan(x)) return 0.0f;
          return int(x * 100.0f / 255.0f);

  - platform: rotary_encoder
    name: "Encoder 1"
    id: encoder1
    pin_a: GPIO10
    pin_b: GPIO11
    resolution: 4
    min_value: 0
    max_value: 100
    on_value:
      then:
        - logger.log:
            level: INFO
            format: "Encoder1 value: %.0f"
            args: ["id(encoder1).state"]
        - homeassistant.service:
            service: light.turn_on
            data:
              entity_id: light.led_controller_1_light_bar
              brightness_pct: !lambda "return id(encoder1).state;"

  - platform: rotary_encoder
    name: "Encoder 2"
    id: encoder2
    pin_a: GPIO15
    pin_b: GPIO16
    resolution: 4
    on_value:
      then:
        - logger.log:
            level: INFO
            format: "Encoder2 value: %.0f"
            args: ["id(encoder2).state"]

  - platform: rotary_encoder
    name: "Encoder 3"
    id: encoder3
    pin_a: GPIO33
    pin_b: GPIO34
    resolution: 4
    on_value:
      then:
        - logger.log:
            level: INFO
            format: "Encoder3 value: %.0f"
            args: ["id(encoder3).state"]

  - platform: rotary_encoder
    name: "Encoder 4"
    id: encoder4
    pin_a: GPIO38
    pin_b: GPIO39
    resolution: 4
    on_value:
      then:
        - logger.log:
            level: INFO
            format: "Encoder4 value: %.0f"
            args: ["id(encoder4).state"]

# SH1106 128×64 over I2C
display:
  - platform: ssd1306_i2c
    model: SH1106 128x64
    id: display1

    address: 0x3D
    rotation: 0
    update_interval: 1000ms
    pages:
      - id: page1
        lambda: |-
          int val1 = int((id(led_controller_1_light_bar_brightness).state / 100.0f) * 31);
          if (val1 != 0) {
            val1 += 1;
          }
          it.filled_rectangle(10, 64-val1, 5, 33);

          // it.printf(0, 0, id(font1), "%.0f%%", id(led_controller_1_light_bar_brightness).state);
      - id: page2
        lambda: |-
          it.print(0, 10, id(font1), "This is page 2!");
          it.filled_rectangle(10, 20, 80, 5);

font:
  - file: "gfonts://Ubuntu"
    id: font1
    size: 20

# captive_portal:
captive_portal:

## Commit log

2025-05-20 add button for D1
2025-08-06 Finish project
    [Button.step, Case.FCStd]
